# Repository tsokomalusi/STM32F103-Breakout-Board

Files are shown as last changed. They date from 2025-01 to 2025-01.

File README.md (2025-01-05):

# STM32F103-Breakout-Board

## Acknowledgements 
The PCB design of this STM32F103 breakout board was inspired by Philip Salmony [Phil's Lab](https://www.youtube.com/watch?v=wLwKgMBWhpY&list=PLXSyc11qLa1b9VA7nw8-DiLRXVhZ2iUN2&index=11).
I reverse-engineered it a bit by adding an SWD connector and ESD protection IC
to  make routing a bit more challenging.

## PCB Layout (2-Layer Design)
pcb_layout

## 3D Overview
### Top View
STM32F103

### Bottom View
STM32F103_B

## JLCPCB Gerber Viewer
simulation_image_top (1)

simulation_image_bottom

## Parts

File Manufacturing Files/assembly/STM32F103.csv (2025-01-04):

Reference | Value | Datasheet | Footprint | Qty | DNP
C1 | 4u7 | ~ | Capacitor_SMD:C_0603_1608Metric | 1
C2,C3,C4,C5,C7 | 100n | ~ | Capacitor_SMD:C_0402_1005Metric | 5
C6,C10,C11 | 1u | ~ | Capacitor_SMD:C_0402_1005Metric | 3
C8,C9 | 30p | ~ | Capacitor_SMD:C_0402_1005Metric | 2
D1 | BLUE | ~ | LED_SMD:LED_0603_1608Metric | 1
D2 | GREEN | ~ | LED_SMD:LED_0603_1608Metric | 1
FB1 | 100R | ~ | Inductor_SMD:L_0805_2012Metric | 1
J1 | USB_B_Micro | ~ | Connector_USB:USB_Micro-B_Wuerth_629105150521 | 1
J2,J3 | Conn_01x15 | ~ | Connector_PinHeader_2.54mm:PinHeader_1x16_P2.54mm_Vertical | 2
J4 | Conn_01x04_Pin | ~ | Connector_PinHeader_2.54mm:PinHeader_1x04_P2.54mm_Vertical | 1
L1 | 27n | ~ | Inductor_SMD:L_0402_1005Metric | 1
R1 | 10k | ~ | Resistor_SMD:R_0402_1005Metric | 1
R2,R3,R4 | 1K5 | ~ | Resistor_SMD:R_0603_1608Metric | 3
U1 | STM32F103C8T6 | https://www.st.com/resource/en/datasheet/stm32f103c8.pdf | Package_QFP:LQFP-48_7x7mm_P0.5mm | 1
U2 | USBLC6-2SC6 | https://www.st.com/resource/en/datasheet/usblc6-2.pdf | Package_TO_SOT_SMD:SOT-23-6 | 1
U3 | XC6206P332MR | https://www.torexsemi.com/file/xc6206/XC6206.pdf | Package_TO_SOT_SMD:SOT-23-3 | 1
Y1 | 8MHz | ~ | Resistor_SMD:R_0402_1005Metric | 1

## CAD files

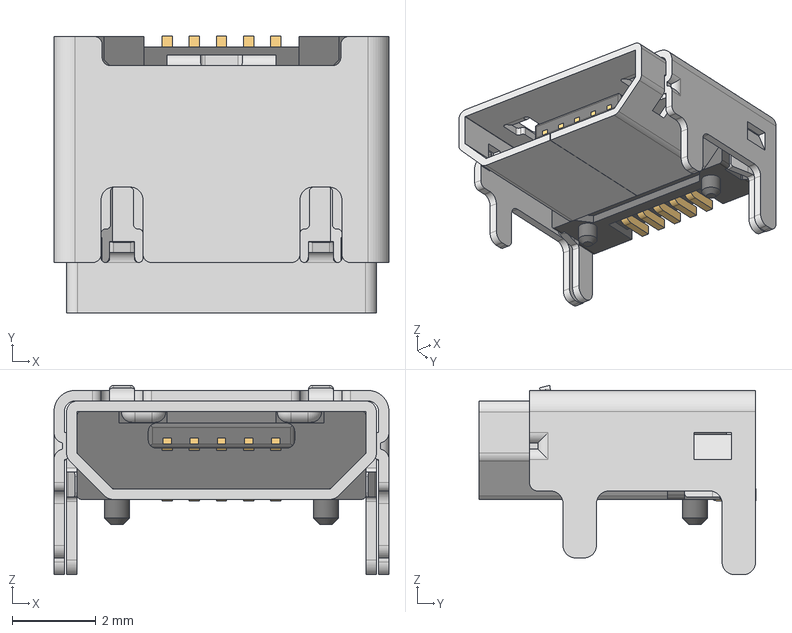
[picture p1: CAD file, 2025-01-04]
step files/Download_STP_629105150521_rev1.stp
8.00 x 6.60 x 4.52 mm
629105150521_Housing
629105150521_Pin1 x 4
629105150521_Pin2
629105150521_Shielding2
629105150521_Shielding

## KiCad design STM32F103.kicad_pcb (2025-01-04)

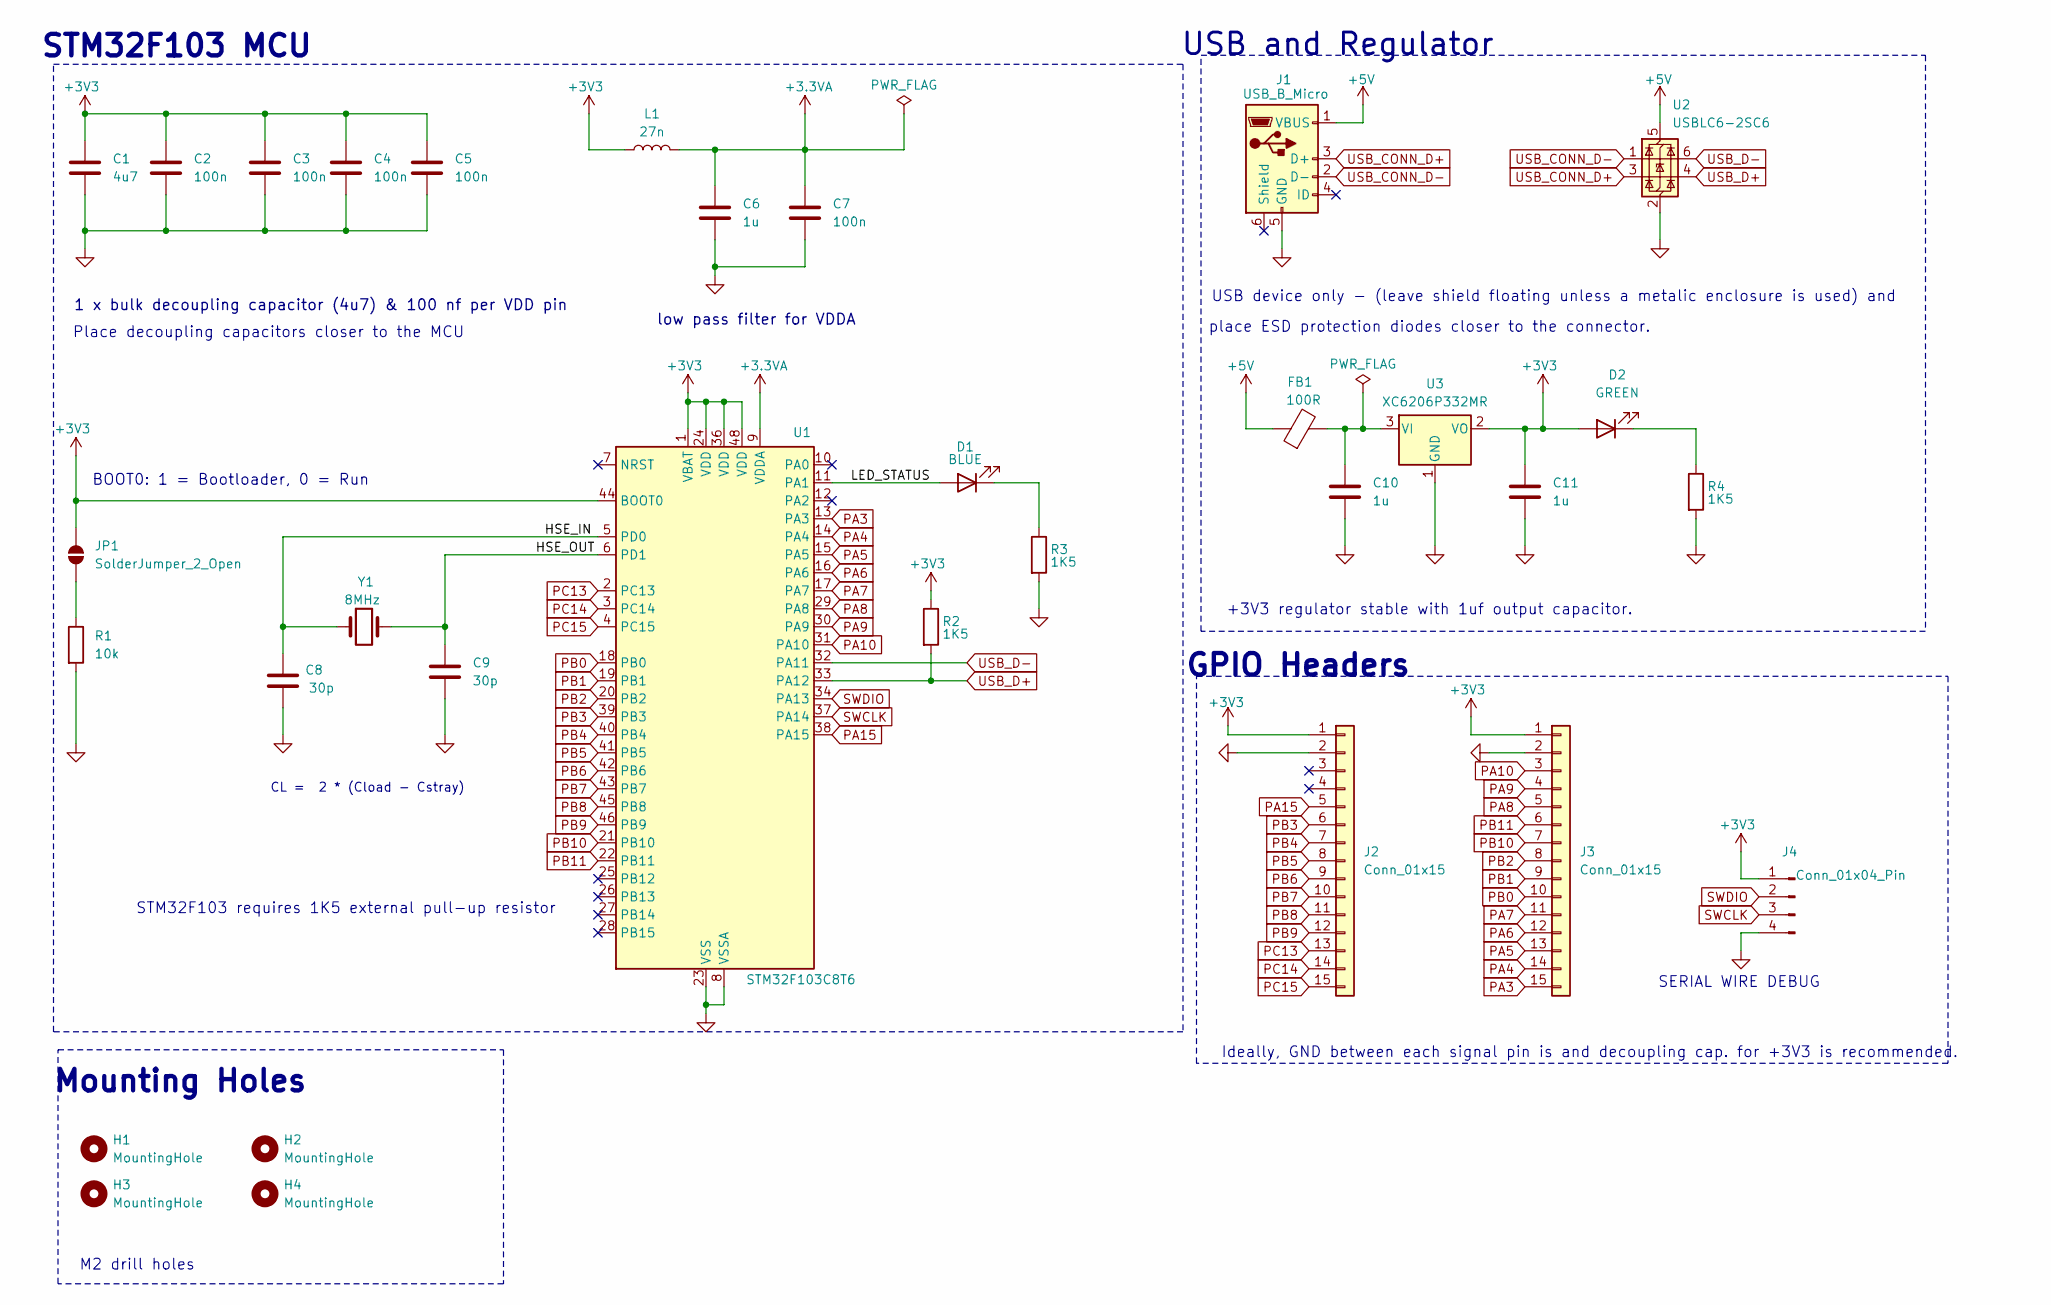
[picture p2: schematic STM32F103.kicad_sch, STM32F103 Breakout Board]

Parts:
C1: 4u7; C_0603_1608Metric
C2, C3, C4, C5, C7: 100n; C_0402_1005Metric
C6, C10, C11: 1u; C_0402_1005Metric
C8, C9: 30p; C_0402_1005Metric
D1: BLUE; LED_0603_1608Metric
D2: GREEN; LED_0603_1608Metric
FB1: 100R; L_0805_2012Metric
H1, H2, H3, H4: MountingHole; MountingHole_2.2mm_M2
J1: USB_B_Micro; USB_Micro-B_Wuerth_629105150521
J2, J3: Conn_01x15; PinHeader_1x16_P2.54mm_Vertical
J4: Conn_01x04_Pin; PinHeader_1x04_P2.54mm_Vertical
JP1: SolderJumper_2_Open; SolderJumper-2_P1.3mm_Open_Pad1.0x1.5mm
L1: 27n; L_0402_1005Metric
R1: 10k; R_0402_1005Metric
R2, R3, R4: 1K5; R_0603_1608Metric
U1: STM32F103C8T6; LQFP-48_7x7mm_P0.5mm
U2: USBLC6-2SC6; SOT-23-6
U3: XC6206P332MR; SOT-23-3
Y1: 8MHz; R_0402_1005Metric

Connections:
+3.3VA: C6.1, C7.1, L1.2, U1.9 (VDDA)
+3V3: C1.1, C2.1, C3.1, C4.1, C5.1, C11.1, D2.2 (A), J2.1, J3.1, J4.1, JP1.2 (B), L1.1, R2.1, U1.1 (VBAT), U1.24 (VDD), U1.36 (VDD), U1.44 (BOOT0), U1.48 (VDD), U3.2 (VO)
+5V: FB1.1, J1.1 (VBUS), U2.5 (VBUS)
/HSE_IN: C8.1, U1.5 (PD0), Y1.1
/HSE_OUT: C9.1, U1.6 (PD1), Y1.2
/LED_STATUS: D1.2 (A), U1.11 (PA1)
GND: C1.2, C2.2, C3.2, C4.2, C5.2, C6.2, C7.2, C8.2, C9.2, C10.2, C11.2, J1.5 (GND), J2.2, J3.2, J4.4, R1.2, R3.2, R4.2, U1.8 (VSSA), U1.23 (VSS), U1.35 (VSS), U1.47 (VSS), U2.2 (GND), U3.1 (GND)
unnamed: D1.1 (K), R3.1
unnamed: D2.1 (K), R4.1
unnamed: JP1.1 (A), R1.1
unnamed: C10.1, FB1.2, U3.3 (VI)
PA3: J3.15, U1.13 (PA3)
PA4: J3.14, U1.14 (PA4)
PA5: J3.13, U1.15 (PA5)
PA6: J3.12, U1.16 (PA6)
PA7: J3.11, U1.17 (PA7)
PA8: J3.5, U1.29 (PA8)
PA9: J3.4, U1.30 (PA9)
PA10: J3.3, U1.31 (PA10)
PA15: J2.5, U1.38 (PA15)
PB0: J3.10, U1.18 (PB0)
PB1: J3.9, U1.19 (PB1)
PB2: J3.8, U1.20 (PB2)
PB3: J2.6, U1.39 (PB3)
PB4: J2.7, U1.40 (PB4)
PB5: J2.8, U1.41 (PB5)
PB6: J2.9, U1.42 (PB6)
PB7: J2.10, U1.43 (PB7)
PB8: J2.11, U1.45 (PB8)
PB9: J2.12, U1.46 (PB9)
PB10: J3.7, U1.21 (PB10)
PB11: J3.6, U1.22 (PB11)
PC13: J2.13, U1.2 (PC13)
PC14: J2.14, U1.3 (PC14)
PC15: J2.15, U1.4 (PC15)
SWCLK: J4.3, U1.37 (PA14)
SWDIO: J4.2, U1.34 (PA13)
USB_CONN_D+: J1.3 (D+), U2.3 (I/O2)
USB_CONN_D-: J1.2 (D-), U2.1 (I/O1)
USB_D+: R2.2, U1.33 (PA12), U2.4 (I/O2)
USB_D-: U1.32 (PA11), U2.6 (I/O1)

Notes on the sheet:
M2 drill holes
SERIAL WIRE DEBUG
GPIO Headers
+3V3 regulator stable with 1uf output capacitor.
USB device only - (leave shield floating unless a metalic enclosure is used) and
CL = 2 * (Cload - Cstray)
Place decoupling capacitors closer to the MCU
low pass filter for VDDA
STM32F103 MCU
place ESD protection diodes closer to the connector.
Ideally, GND between each signal pin is and decoupling cap. for +3V3 is recommended.
BOOT0: 1 = Bootloader, 0 = Run
STM32F103 requires 1K5 external pull-up resistor
Mounting Holes
1 x bulk decoupling capacitor (4u7) & 100 nf per VDD pin
USB and Regulator

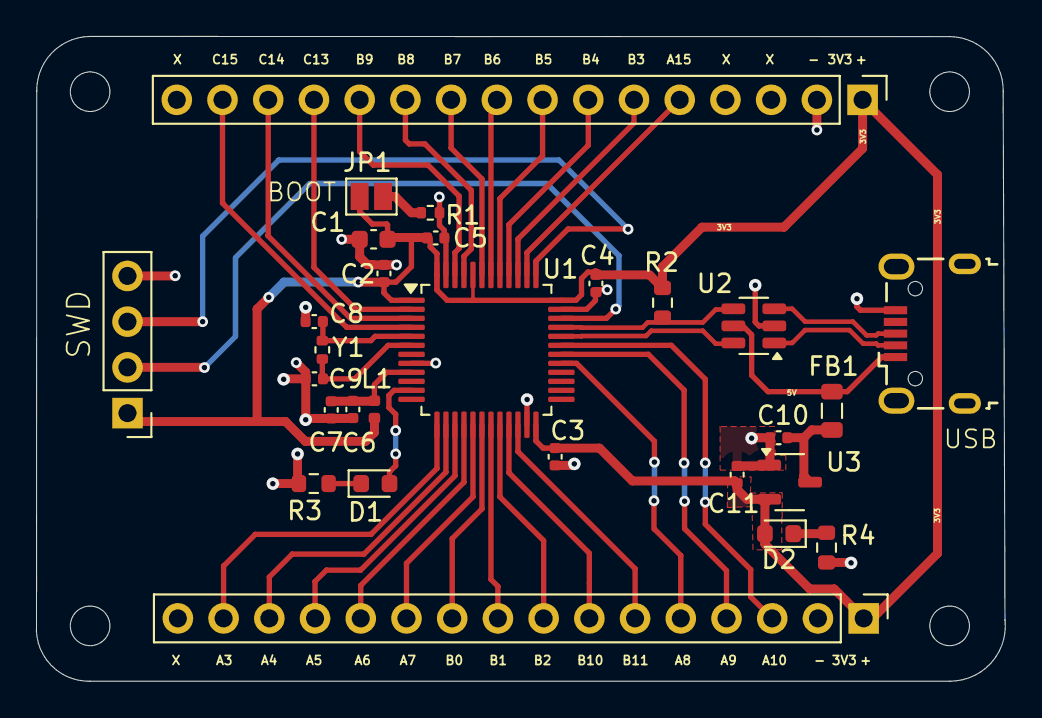
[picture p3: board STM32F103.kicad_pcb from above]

Board: 2 copper layers, 53.8 x 35.8 mm, 32 parts (0 on the bottom side), 41 nets.
